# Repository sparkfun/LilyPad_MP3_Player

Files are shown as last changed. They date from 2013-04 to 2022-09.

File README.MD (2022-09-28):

SparkFun LilyPad MP3
========================================

SparkFun LilyPad MP3 (https://www.sparkfun.com/products/11013)

[*SparkFun LilyPad MP3 (DEV-11013)*](https://www.sparkfun.com/products/11013)

The LilyPad MP3 Player is an amazing little board that contains everything you need to play almost any audio file you wish. You can use it to create MP3-playing hoodies, talking teddy bears, or anything else your imagination can come up with!

### Installation:

You should install the latest version of the Arduino IDE, available at http://www.arduino.cc.

This software requires several nonstandard libraries:
	SdFat (by William Greiman)
	SFEMP3Shield (by Bill Porter)
	pinChangeInt (by Lex Talionis)
	
	The current version of these libraries as of this date are included in this archive.

**TL;DR:** The one-step procedure is to drag the contents of the Arduino folder to your personal Arduino sketch folder. This will create a "libraries" folder (containing support libraries), and a "LilyPad MP3 Player" folder (containing example sketches).

To install the libraries manually, copy the "libraries" folder to your personal Arduino sketch directory. (If there is already a "libraries" folder there, go ahead and add the included libraries to it.) You'll need to restart the Arduino IDE to get it to recognize the new libraries.

To install the example sketches, copy the "LilyPad MP3 Player" folder to your personal Arduino sketch folder.

Loading the sketches:

To load a sketch onto the LilyPad MP3 Player:

1. Connect the LilyPad MP3 Player to your computer using a 5V FTDI board or cable (available at http://www.sparkfun.com). Turn the LilyPad MP3 Player ON. The red LED should light up. Note that a Lipo battery or external power source is required to run the LilyPad MP3 Player.

2. Start the Arduino IDE.

3. Select the correct board type from the menu: Tools / Board / "Arduino Pro or Pro Mini (3.3V, 8MHz) w/ATmega328"

4. Select the correct serial port from the menu: Tools / Serial Port / (the port that your FTDI board or cable has created, usually the highest number)

5. Load the desired sketch into the Arduino IDE.

6. Click on the Upload (right arrow) button at the top of the window. The code should compile then upload to the LilyPad MP3 Player. If you have errors, double-check that you installed the required libraries to the correct place, and restarted the Arduino IDE.

See the tutorials at www.sparkfun.com for more information on using and hacking the LilyPad MP3 Player.

Documentation
--------------
* **[Installing an Arduino Library Guide](https://learn.sparkfun.com/tutorials/installing-an-arduino-library)** - Basic information on how to install an Arduino library.
* **[Hookup Guide](https://learn.sparkfun.com/tutorials/getting-started-with-the-lilypad-mp3-player)** - Basic hookup guide.

License Information
-------------------

This product is _**open source**_! 

Please review the LICENSE.md file for license information. 

If you have any questions or concerns on licensing, please contact support@sparkfun.com.

Distributed as-is; no warranty is given.

- Your friends at SparkFun.

_<COLLABORATION CREDIT>_

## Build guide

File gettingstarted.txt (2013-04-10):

SparkFun Electronics
LilyPad MP3 Player
Getting started guide (DRAFT)

The LilyPad MP3 Player is an amazing little board that contains everything you need to play almost any audio file you wish. You can use it to create MP3-playing hoodies, talking teddy bears, or anything else your imagination can come up with!

Things you'll need

A 5V FTDI BOB or cable
A single-cell (3.7V) Lipo battery (500mAh or above recommended)
Two 4 or 8-Ohm Speakers, or headphones with a 1/8" stereo jack
Conductive thread and sewing supplies, or hook-up wire and soldering tools

Getting started with the default sketch ("Trigger")

The default sketch will wait for one of the five trigger inputs to be grounded, and play the corresponding audio file from the micro-SD card.

1. Put up to five audio files onto a micro-SD card. The board will play a number of audio formats including MP3, WAV, AAC, MID, etc.

2. Rename the files so that the first character of each filename is the number "1" to "5", corresponding to the trigger that you want to play that file. You don't need to change anything else about the filename; just make sure it has one of the standard file extensions for audio types (MP3, WAV, AAC, MID, etc.).

3. Turn off the LilyPad MP3 Player and plug your micro-SD card into the socket. Push it in until it clicks; if you release it, it will stay seated. To remove it, push again until it clicks, and it will pop out when you release it.

4. Connect a headphone to the headphone jack*, or connect speakers to the left and right speaker terminals. (Note that when anything is plugged into the headphone jack, the speaker terminals are disabled. This behavior can be changed if desired).

5. Plug a 3.7V single-cell Lipo battery into the JST connector. Note that a FTDI USB connection will not provide enough power to run the board**, so a battery or other external power source is required.

6. Move the power switch to ON. The red LED should light up.

7. Now, momentarily connect the ground sew tap (marked GND) to one of the trigger terminals (marked T1 through T5). The audio file associated with that terminal should play through the speakers / headphone. If you don't hear anything, see the troubleshooting section below.

8. To charge the battery or reprogram the board, connect a 5 volt FTDI board to the FTDI header. The yellow LED will light up while the battery is charging, and go out when it's full. To reprogram the board, make sure it's turned on.

9. Have fun!

Getting started with the "Player" sketch

The "Player" sketch is not preprogrammed onto the LilyPad MP3 Player, but you can easily install it using the free Arduino IDE. It is included with the LilyPad MP3 software which you can download from the product page at SparkFun.com.

The Player sketch turns the LilyPad MP3 Player into a full audio player, allowing you to easily switch between tracks and change the volume. The user interface is a rotary encoder (a knob with a built-in pushbutton) available from SparkFun.com that you'll solder onto the LilyPad MP3 Player board.

Things you'll need to run the Player sketch:

RGB Rotary Encoder (SparkFun part no. COM-10982)
(Optional) Clear Plastic Knob (SparkFun part no. COM-10597)
Soldering tools

1. Insert the Rotary Encoder's pins into the holes in the center of the LilyPad MP3 Player. Note that it goes into the "top" side of the board (the side with the white outline).

2. Flip the board over, and solder the encoder's pins to the board. (Don't know how to solder? It's easy, see the tutorials at SparkFun.com).

3. If you haven't, install the free Arduino IDE available from www.arduino.cc, and install the LilyPad MP3 Player software available from SparkFun.com. Note that several new libraries will need to be copied to your "libraries" folder.

4. Connect a 5V FTDI board or cable to the LilyPad MP3 Player, turn on the power switch on the board, and use the Arduino IDE to upload the "Player" sketch to the board.

5. Place the audio files of your choice on a micro-SD card. The LilyPad MP3 Player understands a wide variety of audio types; just make sure your files have one of the standard file extensions (MP3, WAV, AAC, MID, etc.).

6. Turn off the LilyPad MP3 Player, and plug your micro-SD card into socket. Push it in until it clicks; if you release it, it will stay seated. To remove it, push again until it clicks, and it will pop out when you release it.

7. Connect a headphone to the headphone jack*, or connect speakers to the left and right speaker terminals. (Note that when anything is plugged into the headphone jack, the speaker terminals are disabled. This behavior can be changed if desired).

8. Plug a 3.7V single-cell Lipo battery into the JST connector. Note that a FTDI USB connection will not provide enough power to run the board**, so a battery or other external power source is required.

9. Move the power switch to ON. The red LED should light up, and after a few seconds, the rotary encoder will turn red, indicating the player is in "track" mode. (If the rotary encoder blinks, there was a startup problem, see the troubleshooting tips below.)

10. Play music! Here's how:

At any time, to start and stop playback, briefly press the rotary encoder button. When a track has finished playing, the next track will automatically start.

To switch between "track" and "volume" modes, hold the rotary encoder button down until the color changes (one second). Red = track mode, green = volume mode.

In track mode, you can turn the knob forwards or backwards to change tracks (one track per "click" of the knob). If you're currently playing, turning the knob will stop the current track and switch to the next / previous one. If you're not playing, the player will silently keep track of how many clicks you've made.

In volume mode, you can turn the knob forwards or backwards to change the volume.

11. To charge the battery or reprogram the board, connect a 5 volt FTDI board to the FTDI header. The yellow LED will light up while the battery is charging, and go out when it's full. To reprogram the board, make sure it's turned on.

12. Have fun!

Notes

* The LilyPad MP3 Player's headphone jack is safe for headphones, but don't connect it to an external amplifier unless you're using a battery to power the LilyPad. (The fine print is that if the audio ground is shorted to the power ground, the audio decoder chip will be damaged).

** The FTDI port is provided to charge an attached Lipo battery and provide a way to reprogram the board. It will power the board if no audio is playing, but will not provide enough power to drive the speakers. In general, the best way to power the LilyPad MP3 Player is with a Lipo battery. If you'd like to use an external 3.5V - 6V supply, you can do so through the battery connector.

More about the connections

Triggers

In the default Trigger sketch, the five trigger inputs are used to start playing a selected audio file. These inputs are triggered when they are connected to the ground pin (GND), and remain untriggered if they are left "open" or disconnected. You can connect the triggers to ground through “soft switches” to allow your project to play audio clips!

Aside from being triggers, all of the trigger pins have alternate uses. When you write your own sketches, you can use these pins to connect to other devices such as accelerometers, displays, etc.

T1	Trigger 1 input. This can also be used as an analog input (A0).
T2	Trigger 2 input. This can also be used with the Wire (I2C) library as the SDA pin.
T3	Trigger 3 input. This can also be used with the Wire (I2C) library as the SCL pin.
T4	Trigger 4 input. This can also be used as a serial TX pin.
T5	Trigger 5 input. This can also be used as a serial RX pin.

Note that triggers 4 and 5 are shared by the Arduino's serial port, which is used to upload sketches to the board. You can leave soft switches connected to these triggers and upload sketches to the board AS LONG AS the switches stay "untriggered" (not connected to ground) WHILE you're uploading code.

Power

Normally, you'll just connect a 3.7V Lipo battery to the LilyPad MP3 Player, and won't need any of the additional power connections (except the ground pin for your triggers). But if you want to power the board some other way, these pins give you options to do so.

If you already have a regulated 3.3V supply, you can connect it to the 3.3V pin. (This pin will also provide a regulated 3.3V output when the board is operating.) Note that the LilyPad MP3 Player can draw several hundred milliamps when running at full volume.

If you have an unregulated supply in the 3.5V to 6V range, and you want to use it to charge an attached Lipo battery, you can connect it to the VIN pin. If you want to use a 3.5V to 6V source instead of a Lipo battery, connect it to the battery connector or +/- header next to the connector. (This will bypass the charge circuitry). Don't connect a power source to the battery terminals while a battery is connected.

GND	Common ground connection
VIN	Input to battery charger (also connected to FTDI VCC pin)
Battery	Input to circuitry (do not connect a battery at the same time) 
3.3V	Regulated 3.3V input or output

Speakers

The LilyPad MP3 Player includes a stereo class-D audio amplifier for driving speakers. It will drive speakers from 4 to 16 ohms, and the amplifier can output up to 0.75 watts per channel.

We've had good luck with speakers of all sizes, but in general larger speakers will sound better. (TIP: You can often make smaller speakers sound better if you put some sort of enclosed cavity behind them). You can also connect multiple speakers in series or parallel for each channel, as long as the total load is between 4 and 16 ohms.

The speaker outputs are a high-efficiency PWM signal designed only for speakers. Don't connect the speaker outputs to anything besides speakers or other coil-based transducers. Also ensure that you don't connect the speaker outputs together, to each other, or to ground.

If you want to connect the LilyPad MP3 Player to an external amplifier, you can use the headphone jack, but be careful: the audio ground is not the same as the power ground, and if those two are connected the MP3 decoding chip will be damaged. This generally means that the LilyPad MP3 Player and your external amplifier should be running on separate power supplies. If you're running the LilyPad on a Lipo battery, this should be safe. Note that if you're exclusively using the headphone jack, you can disable the amplifier in your sketch to save power.

TIP: Speakers have two terminals, sometimes they're labeled + and -, and sometimes they're not labeled at all. Speakers are non-polarized; they'll work equally well connected in either direction, but if you're using more than one speaker, try to connect both of them the same way. If one is reversed from the other, you may hear strange phasing effects in the audio (which might be what you want after all!).

Battery charging

To charge an attached Lipo battery, plug a 5V FTDI board or cable into the FTDI header. The battery will charge whether the board is on or off, but the battery will charge somewhat faster while the board is off.

The yellow charge LED will light while the battery is charging, and go out when the battery is full. It is normal for the charge LED to light if there is no battery connected.

When an empty battery starts charging, the charger chip will get warm. This is normal. It will run cooler as the battery approaches full charge.

The battery charger is set to a charge rate of 500mA (the maximum provided by a USB port). This means that an empty 500mAh battery will recharge in one hour; a 1000mAh battery will recharge in two hours, etc.

If you wish, you can change the charge rate by changing resistor R1. You may want to do this to avoid charging the battery too quickly if you're using a smaller battery than 500mAh. (SparkFun Lipo batteries do not like to be charged faster than one hour.) To change the charge rate, use a soldering iron to discard the small surface-mount resistor in the box marked R1 near the power switch. Then solder in a through-hole resistor of the proper size. The formula to determine the proper resistance is: R = 1000 / desired current in Amps. For the default current of 500mA (0.5A), a 2000 Ohm resistor is used. If you want to use a 110mAh battery, you'll want a charge rate of 110mA (0.110A), which requires a 9090 Ohm resistor. The closest standard resistor value is 9.1K, but an easier-to-find 10K resistor would give you a charge rate of 100mA, which is safe.

Programming

The LilyPad MP3 Player example sketches require several additional libraries. These libraries are included in the LilyPad MP3 Player archive; before programming the board, drag the libraries from the archive into a "libraries" folder within your Arduino sketch folder.

The LilyPad MP3 Player must be turned ON to program it.

Set your Arduino IDE's Tools/Board setting to "Arduino Pro or Pro Mini (3.3V, 8MHz) w/ ATmega328".

The example code (Trigger and Player) are great starting points for writing your own code. Also see the code in the LilyPad MP3 Player "examples" directory.

Troubleshooting

If the board can't find a properly-formatted SD card, it will blink the red LED in the rotary encoder. (If you don't have a rotary encoder installed, you can stick the leads from a LED into the two end holes in the row of five holes in the rotary encoder footprint.) If this happens, double-check that a micro-SD card is plugged in, and that it's properly formatted (FAT or FAT32).

If the red power LED turns on but you can't get it to play any sounds, double-check that: there are audio files present on the SD card, that the extensions of the files are a playable type (MP3, WAV, etc.), and if you're using the trigger sketch, that the first character in the filename is a number from 1 to 5. Also check that you're making a good connection between GND and the trigger pin (an alligator cable is a good way to check this).

If the player stops in the middle of a song, ensure that you're using a full Lipo battery.

Tips

Note that the board requires a 5V (not a 3.3V) FTDI BOB or cable.

Don't connect the speaker outputs together, to ground, or to anything that isn't a speaker or coil-based transducer.

Use a full battery; if the voltage gets too low the LilyPad MP3 Player may lock up (you can turn it off and on to restart it).

Only insert or eject the SD card when the LilyPad MP3 Player is powered off.

Before washing a garment or project containing the LilyPad MP3 Player, follow these steps:

1.Remove the Lipo battery
2.Remove the micro-SD card
3.Wash by hand
4.Allow to fully air dry (over several days) before powering up again

Have fun!

-Your friends at SparkFun.

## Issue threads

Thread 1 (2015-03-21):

I dont know why this keeps coming up. Help!

jso-07, 2015-03-21:
Arduino: 1.6.1 (Mac OS X), Board: "LilyPad Arduino, ATmega328"

/Users/jasmineangelaso/Documents/Arduino/libraries/SFEMP3Shield/SFEMP3Shield.cpp:25:37: error: variable 'bitrate_table' must be const in order to be put into read-only section by means of '__attribute__((progmem))'
 PROGMEM uint16_t bitrate_table[15][6] = {
                                     ^
Error compiling.

  This report would have more information with
  "Show verbose output during compilation"
  enabled in File > Preferences.

embeddedgenius, 2015-08-12:
I'm getting this error as well.  How do you resolve this?

mgrusin, 2016-02-29:
We've updated the SFE MP3 Player library included in this repository to the most recent version, which fixes the above issue and should compile cleanly in recent Arduino IDEs (1.6.7 etc.) Please let us know if you run into further problems.

Closed 2016-02-29.

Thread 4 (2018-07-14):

Player - 'Next Track' issues

Joshoeah, 2018-07-14:
Hi there,

As discussed with Sparkfun support, Player.ino appears to have issues with moving to the next track. Using a Lilypad MP3 with two speakers connected and an SD Card formatted to FAT32 with 7 files on it (all MP3):

**Whilst playing**
-  Turning rotary encoder CW results in it skipping from whichever track is playing to Track 1, then Track 5, then Track 1, then back to Track 5 - it never selects any other track.

- Allowing a track to play through and 'advance' to the next one automatically results in the same behaviour - Track 1, 5, 1, 5 over and over.

- Turning rotary encoder CCW results in skipping to 'previous' track exactly as expected. I anticipate this is due to the different code used to search 'backwards' through the SD card.

**Whilst not playing** (monitored through Serial)
- Turning rotary encoder either direction results in the device correctly moving through tracks sequentially - exactly as expected.

I have observed no other issues outside of this - though looking through the code I simply cannot see why I'm experiencing this problem. I have even monitored HEX values of the encoder and these are consistent - whether playing or not - so it does not appear to be an issue with the encoder or the code controlling it. Rather, it appears this issue is with selecting the next file on the SD Card.

I have noticed some of the libraries have been updated since this code was posted here and on the Sparkfun site - I tried to update these in the Arduino IDE, but this resulted in errors regarding SDFatUtil and the code would no longer compile.

Hope that's enough information for you / you might be able to help with narrowing this issue down - I'm a bit lost!

mgrusin, 2018-07-14:
Hi Josh, that's an excellent bug report, and a mysterious one. I'll be sure to take a look at this next week, but in the meantime you might turn on serial debugging output at the top of the code to see if it prints out any clues. There could also be something weird with the SD card. You might try low-level formatting it, and also see if you can read all the files off of it on a normal computer.

Joshoeah, 2018-07-14:
Hey Mike - thanks for the help. Can confirm I've formatted the SD card a few times on various computers just to check and tried an alternative one too - had no luck either way so far. Serial debugging doesn't seem to show up anything unusual - everything starts up as expected with no error messages. Switching between tracks (whether CW or CCW) whilst playing gives the usual 'Stopping playback' and then next file name.
Just in case - I'll grab a fresh SD card and try some alternative files and will reply here if I have any luck. Thanks in advance for any light you might be able to shed on the matter! Let me know if I can pull any extra info from the serial monitor for you.

Joshoeah, 2018-07-14:
Quick update: fresh 1GB SD, tested formatted as both FAT and FAT32 - exactly the same behaviour, no changes in either case.

mgrusin, 2018-07-16:
Hi Josh, give the Rotary_Encoder_Demo.ino a try (in examples) when you get a chance. With the serial window open to 9600 baud it should show smooth operation of the rotary encoder. If it doesn't there may be a hardware problem with the encoder, which could explain some of this behavior.

It's worth noting that the player sketch doesn't do any alphabetizing of the files it finds; it plays them in the order in which they're physically stored on the SD card. To get them to play in a specific order you might try formatting the card then copying your files to it one-by-one in the order you prefer.

The way player works, especially when you want the previous file (for which there is no SDfat function) was always a little hacky due to the primitive way SDfat traverses directories. I do recall seeing that SDfat had completely changed some of their routines (hopefully for the better) but since that thoroughly broke the existing software we haven't gone back to rewrite everything. It might be time to do that now. But if you use all of the libraries included in this repo (deleting newer ones from your libraries folder to avoid confusion) it "should" work.

Let me know what you find.

Joshoeah, 2018-07-16:
Hey Mike, I gave Rotary_Encoder_Demo.ino a shot just now and the encoder spins smoothly - numbers increase as far as I turn it, then decrease the other way. No issues with button press (or hold) - all behaving as expected.

Ahh I got'cha - I did wonder! Either way, moving forward (CW) whilst playing just runs the first three tracks it finds on the card (1, 6, then 2 in this case) before looping back to 1 again. The things I find most strange is getNextTrack clearly has no issues moving through files - it smoothly moves from track to track when playback is paused as well as when moving backwards through the tracks (CCW on the encoder).

I've since reverted to the libraries you have here as suggested. I don't think I'm capable enough to rewrite this with the new libraries - I got lost when I did try - but I could try and hack something together. The prop I'm building is for an event on the 5th of August, so if necessary I'll just ensure it's used to skip through tracks backwards and forego going forwards - only problem with this being when it reaches the end of a track it'll revert back to the 1,2,6 loop. If all else fails I might just have to make a singular long MP3 with all of the files in the order required - that'll work 100% :)

Thanks for the help!

Joshoeah, 2018-07-17:
Okay - got it! Managed to get it to compile using the latest version of SdFat (updated direct from the Library Manager) and **that's fixed it!** Tracks now smoothly advance sequentially whether using the encoder or when reaching the end of a track.

Steps taken for future reference (probably hacky, but hey, it works):

- Removed \#include SdFatUtil.h from **SFEMP3Shield.h** - not used in new SdFat library
- Removed \#include SdFatUtil.h from **Player.ino** - not used in new SdFat library
- Changed **Line 611 in Player.ino**, amending file.getFileName(track) to file.getName(track,13). This is the key change that got it working with the new SdFat, since getFileName has been deprecated. file.getName has a new parameter for length, hence the 13. Not sure if this is the right way to do it, but it works!

Worth noting that SdFat now supports long names, so the full track name could be pulled - if this is of use to anyone in the future.

I did have a funny issue with 'FreeRam' in line 186 - the code would no longer compile and started throwing errors about this not being defined. Since it wasn't critical, I've just commented it out for now.

Hope this helps anybody in future - the changes were ultimately quite simple to make and the sketch now works perfectly!

Joshoeah, 2018-07-18:
Quick supplementary comment to this - my files were ultimately stored with the naming format 1.mp3, 2.mp3, 3.mp3, etc... I found that longer names were a bit unreliable and could result in the track being skipped. **I imagine this is due to me specifying length parameter as '13'** - though I admittedly have not had chance to check since the Lilypad has been secured into the prop.

**I also noted issues with tracks not starting immediately** - seemingly taking a long time to 'load', with several seconds of silence between them. **This was resolved by using [MP3tag](https://www.mp3tag.de/en/index.html) to strip every bit of metadata**, including any cover art, from the files. After doing so I found files loaded instantly and skipping / playing seemed far more responsive.

mgrusin, 2018-07-18:
Hi Josh, well done! I'm very glad you got it working, and thank you for giving us the steps it took to do so. I believe your solution will work as long as you don't have two filenames that share the same first 13 characters; otherwise it may have problems finding the previous file. But that's an easy enough restriction to work around. When I have time I'll dig into the new SDfat and update everything. Thanks again and again nicely done.

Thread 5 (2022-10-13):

playMP3(fileName, timecode)

JonGordon123, 2022-10-13:
Arduino 1.8.19
LilyPad MP3

I was having a few issues when attempting to play an mp3 from a specified ms time and found the following.

1) The variable "**bitrate**" is declared in SFEMP3Shield.h as a uint8_t, which only allows bitrates up to 224kbps. I changed it to uint16_t which solves that issue.

2) The If...else if... else if... else statement found in the **getBitRateFromMP3File(filename)** function (SFEMP3Shield.cpp) seems to not be functioning as, I imagine, it should be. If the MP3 file is MPEG Version 2/2.5 then the first if statement evaluates true, and no other code is run in the if/else if block.... causing the "bitrate" variable to be filled with an incorrect bitrate.
I tested with multiple files, bitrates, and sample rates and was getting incorrect bitrates often.
```
 //found the 11 1's
  //parse version, layer and bitrate out and save bitrate
  if(!(temp & 0b00001000)) { //!true if Version 1, !false version 2 and 2.5
    row_num = 3;
  }
  else if((temp & 0b00000110) == 0b00000100) { //true if layer 2, false if layer 1 or 3
    row_num += 1;
  }
  else if((temp & 0b00000110) == 0b00000010) { //true if layer 3, false if layer 2 or 1
    row_num += 2;
  } else {
    continue; // Not found, need to skip the rest and continue looking.
              // \warning But this can lead to a dead end and file end of file.
  }
```

**I seem to have fixed my issue by replacing the existing if...else if....else if...else with the following.**

```
bool nobits = true;

if(!(temp & 0b00001000)) {
   // MPEG Version 2 or 2.5
   row_num = 3;
   nobits = false;
}
if((temp & 0b00000110) == 0b00000110) {
  // Layer 1
  row_num += 0;
  nobits = false;
}
if((temp & 0b00000110) == 0b00000100) {
  // Layer 2
  row_num += 1;
  nobits = false;
}
if((temp & 0b00000110) == 0b00000010) {
  // Layer 3
  row_num += 2;
  nobits = false;
}
if(nobits){
  continue;
}
```

These two changes allowed me to play any file from any ms timestamp, without issue.

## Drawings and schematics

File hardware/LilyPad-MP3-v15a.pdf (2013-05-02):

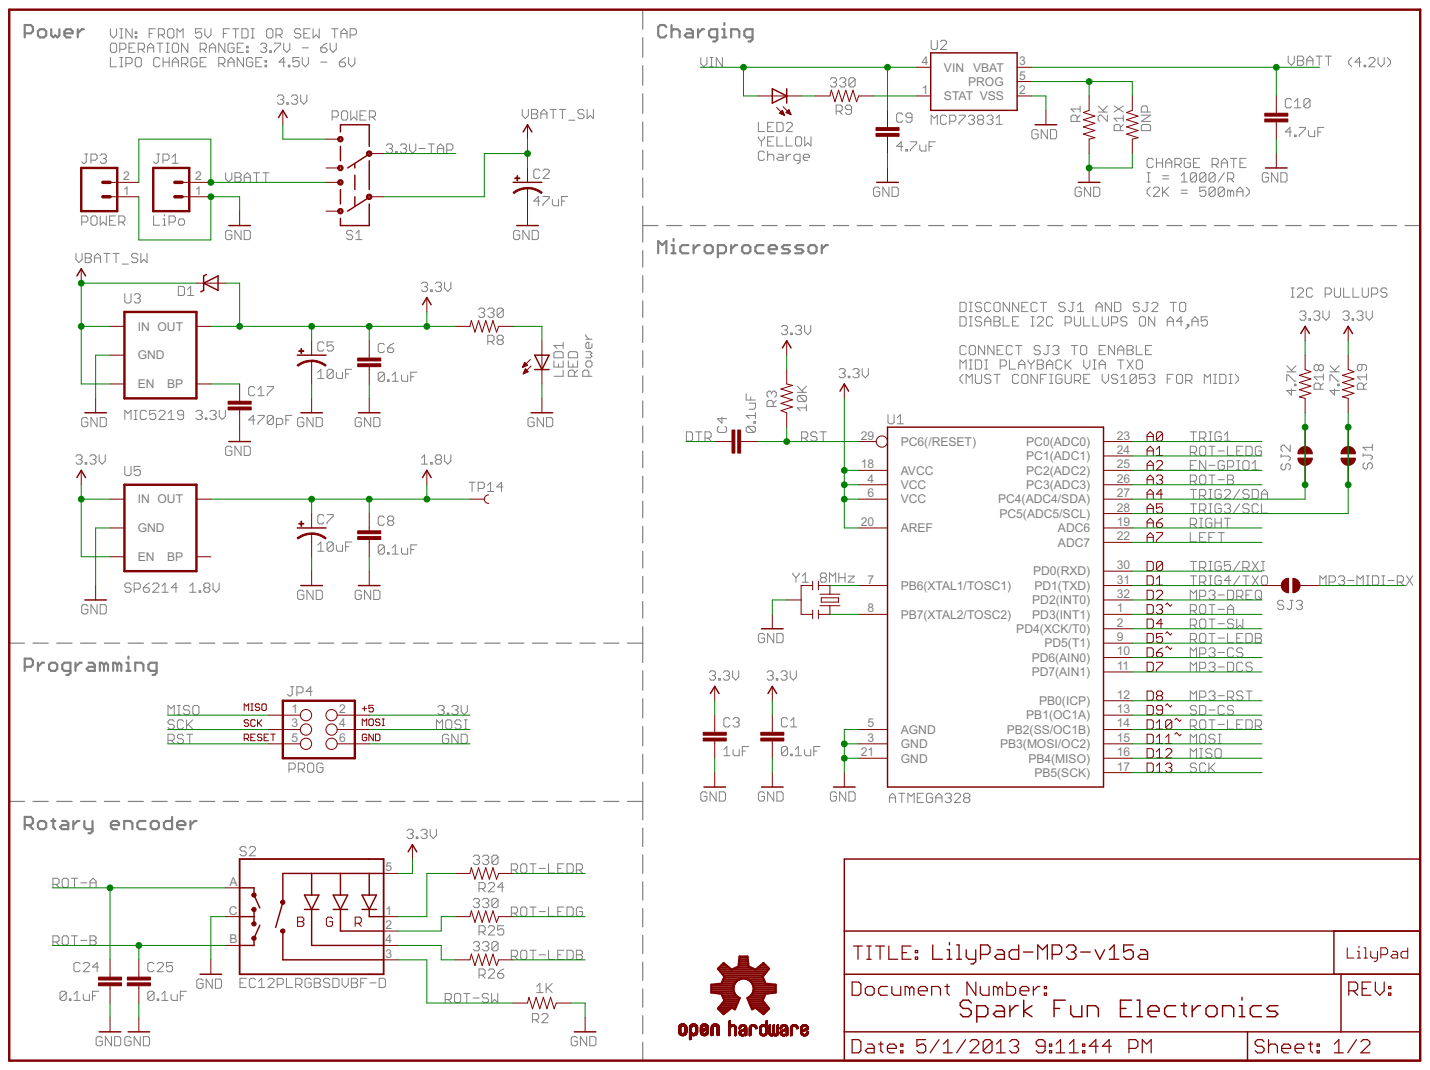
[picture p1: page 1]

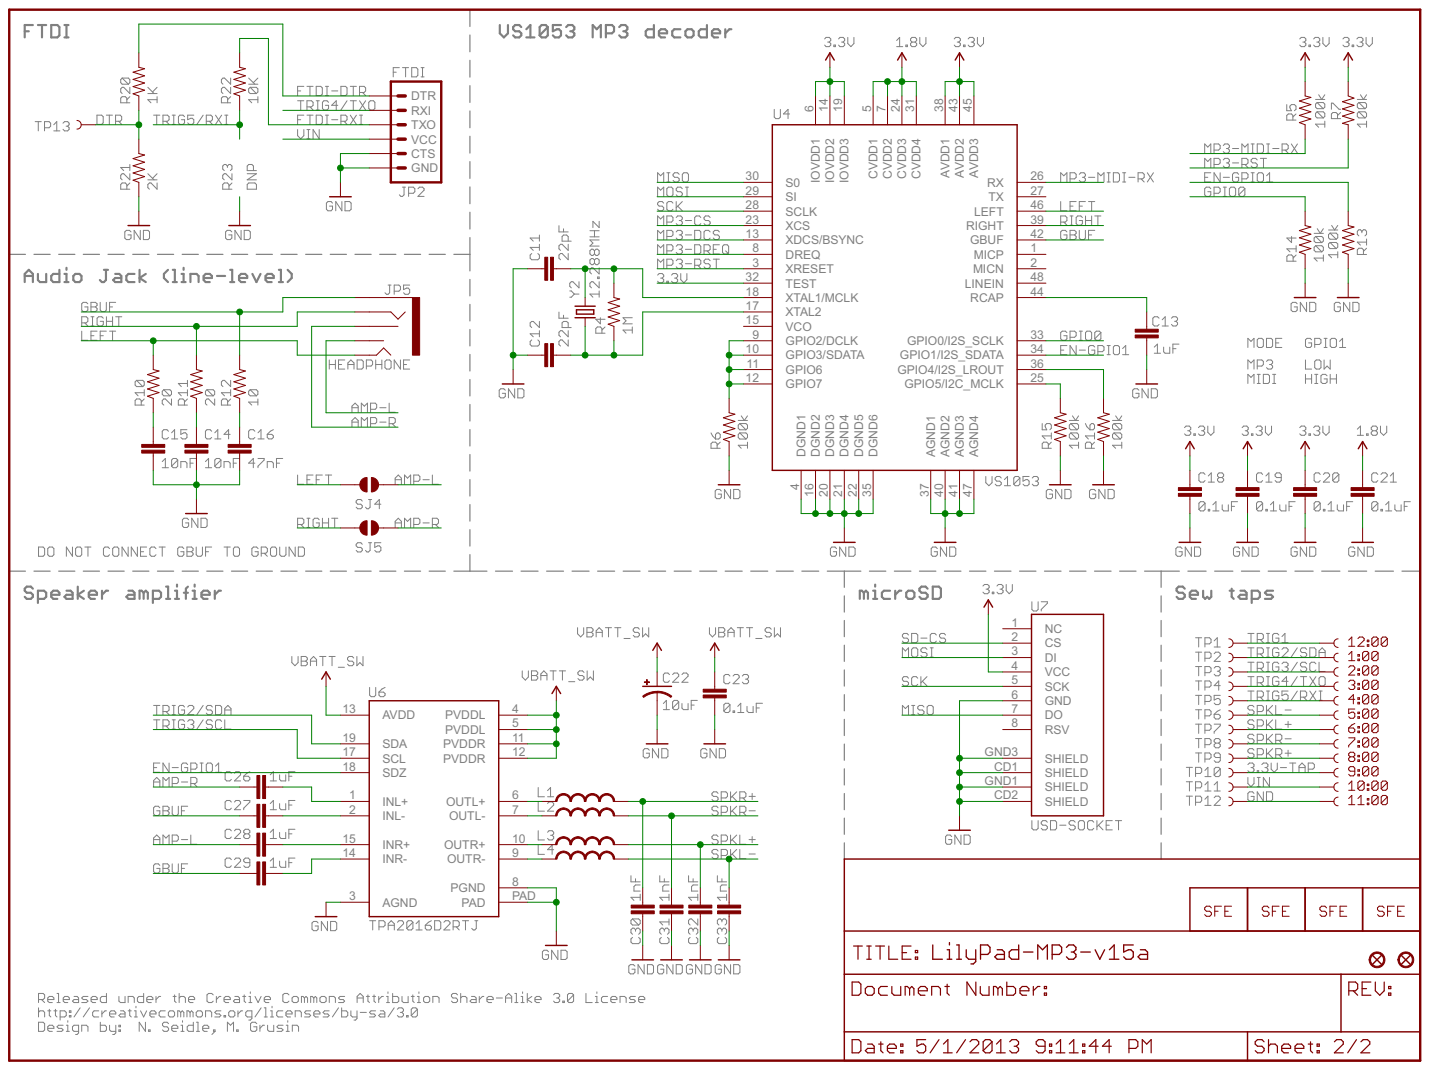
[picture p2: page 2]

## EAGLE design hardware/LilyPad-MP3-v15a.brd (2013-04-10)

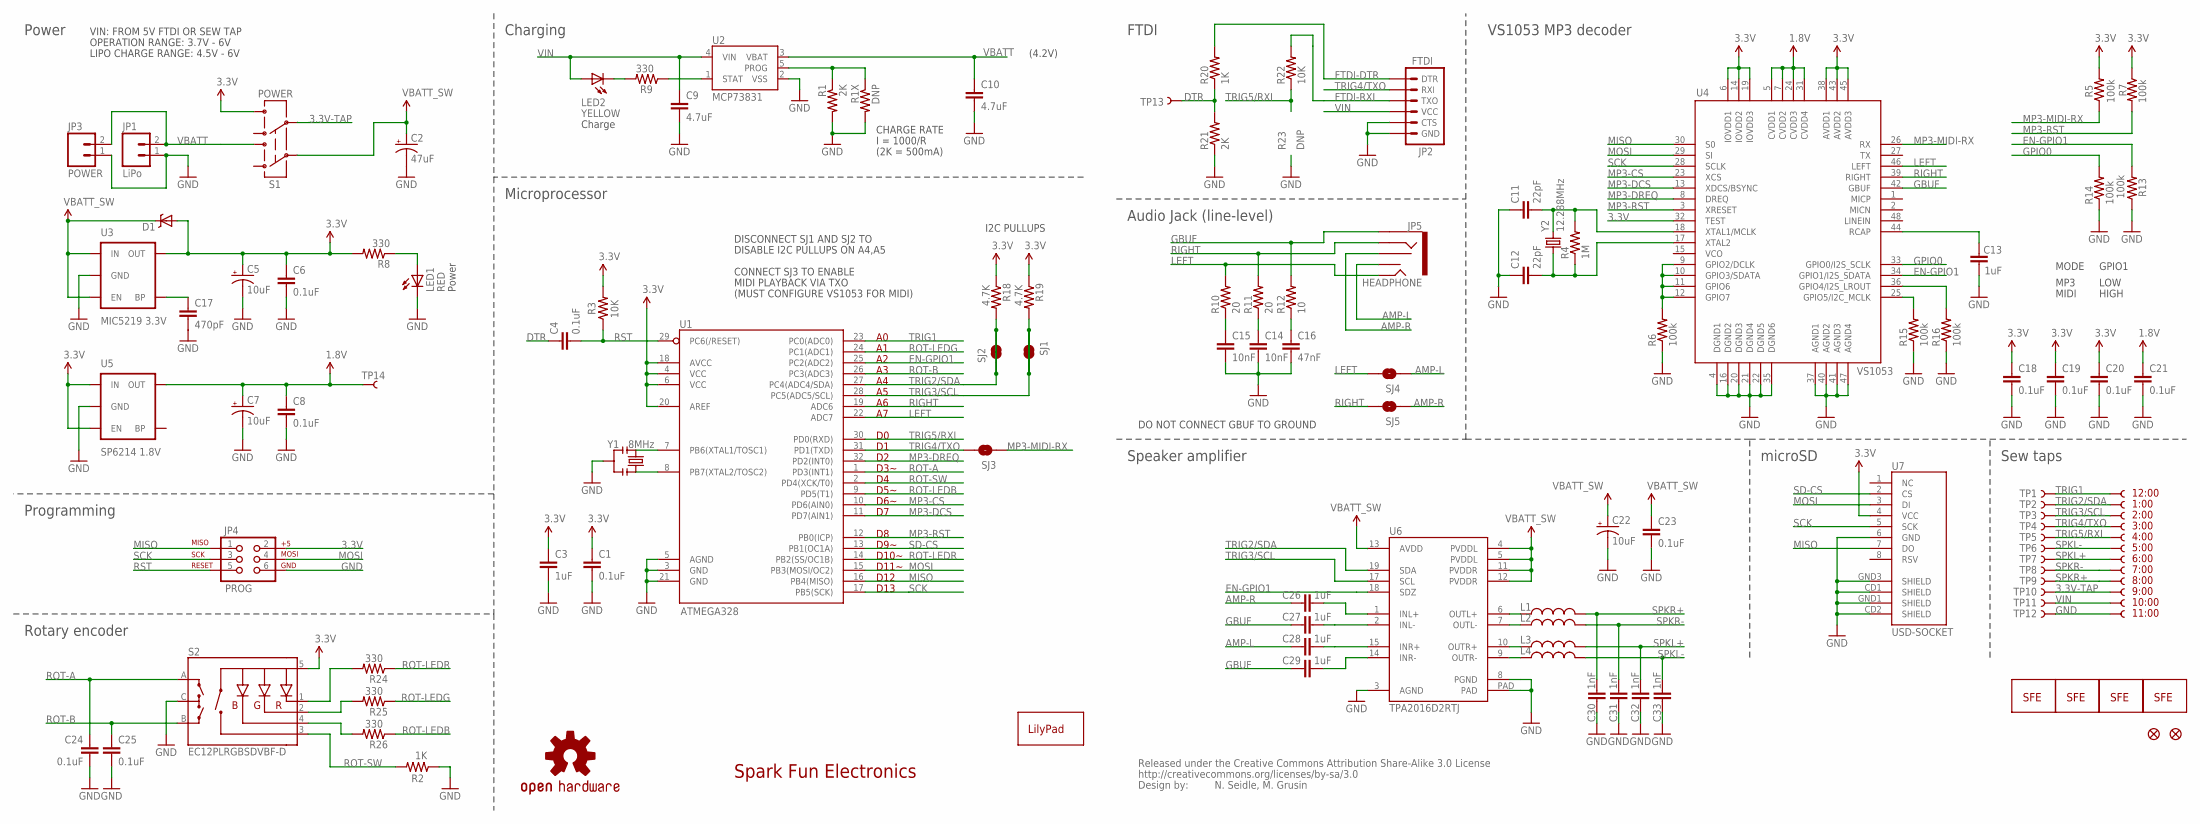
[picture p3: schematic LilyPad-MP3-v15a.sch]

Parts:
C1, C4, C6, C8, C18, C19, C20, C21, C23, C24, C25: 0.1uF; 0402-CAP
C2: 47uF; EIA3528
C3, C13, C26, C27, C28, C29: 1uF; 0402-CAP
C5, C7, C22: 10uF; EIA3216
C9, C10: 4.7uF; 0402-CAP
C11, C12: 22pF; 0402-CAP
C14, C15: 10nF; 0402-CAP
C16: 47nF; 0402-CAP
C17: 470pF; 0402-CAP
C30, C31, C32, C33: 1nF; 0402-CAP
D1: DIODE-SCHOTTKY; SOD-523
JP1: LiPo; JST-2-SMD
JP2: FTDI; 1X06-SMD
JP3: POWER; 1X02
JP4: PROG; 2X3-NS
JP5: HEADPHONE; AUDIO-JACK-3.5MM-SMD
JP6: LOGO-SFENW2; SFE-NEW-WEB
JP7, JP8: FIDUCIALUFIDUCIAL; MICRO-FIDUCIAL
L1, L2, L3, L4: INDUCTOR0805; 0805
LED1: RED; LED-0603
LED2: YELLOW; LED-0603
LOGO1, LOGO3: LOGO-SFESK; SFE-LOGO-FLAME
LOGO2: LOGO-SFENEW; SFE-NEW-WEBLOGO
R1, R21: 2K; 0402-RES
R1X: DNP; AXIAL-0.3
R2, R20: 1K; 0402-RES
R3, R22: 10K; 0402-RES
R4: 1M; 0402-RES
R5, R6, R7, R13, R14, R15, R16: 100k; 0402-RES
R8, R9, R24, R25, R26: 330; 0402-RES
R10, R11: 20; 0402-RES
R12: 10; 0402-RES
R18, R19: 4.7K; 0402-RES
S1: POWER; AYZ0202
S2: EC12PLRGBSDVBF-D; ENCODER_LED_3
SJ1, SJ2, SJ3, SJ4, SJ5: SOLDERJUMPERNO; SJ_2S-NO
ST1: TRIG2/SDA; PETAL-LONG-1-2SIDE
ST2: TRIG3/SCL; PETAL-LONG-1-2SIDE
ST3: TRIG4/TXO; PETAL-LONG-1-2SIDE
ST4: TRIG5/RXI; PETAL-LONG-1-2SIDE
ST5: SPKL-; PETAL-LONG-1-2SIDE
ST6: SPKL+; PETAL-LONG-1-2SIDE
ST7: SPKR-; PETAL-LONG-1-2SIDE
ST8: SPKR+; PETAL-LONG-1-2SIDE
ST9: 3.3V; PETAL-LONG-1-2SIDE
ST10: VIN; PETAL-LONG-1-2SIDE
ST11: GND; PETAL-LONG-1-2SIDE
ST12: TRIG1; PETAL-LONG-1-2SIDE
TP1: TRIG1; 1X01NS
TP2: TRIG2/SDA; 1X01NS
TP3: TRIG3/SCL; 1X01NS
TP4: TRIG4/TXO; 1X01NS
TP5: TRIG5/RXI; 1X01NS
TP6: SPKL-; 1X01NS
TP7: SPKL+; 1X01NS
TP8: SPKR-; 1X01NS
TP9: SPKR+; 1X01NS
TP10: 3.3V; 1X01NS
TP11: VIN; 1X01NS
TP12: GND; 1X01NS
TP13: DTR; PAD.03X.05
TP14: 1.8V; PAD.03X.05
U1: ATMEGA328; TQFP32-08
U2: MCP73831; SOT23-5
U3: MIC5219 3.3V; SOT23-5
U4: VS1053; LQFP-48
U5: SP6214 1.8V; SC70
U6: TPA2016D2RTJ; QFN-20-0.5MM
U7: USD-SOCKET; MICRO-SD-SOCKET-PP
U$1: LOGO-LPLP; LOGO-LILYPAD
U$4: OSHW-LOGOM; OSHW-LOGO-M
U$12: CREATIVE_COMMONS
Y1: 8MHz; RESONATOR-SMD
Y2: 12.288MHz; CRYSTAL-SMD-5X3

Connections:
1.8V: C7.A (+), C8.1, C21.1, TP14.P$1, U4.5 (CVDD1), U4.7 (CVDD2), U4.24 (CVDD3), U4.31 (CVDD4), U5.5 (OUT)
3.3V: C1.1, C3.1, C5.A (+), C6.1, C18.1, C19.1, C20.1, D1.A, JP4.2, R3.2, R5.2, R7.1, R8.2, R18.1, R19.1, S1.4 (6), S2.5 (+), U1.4 (VCC), U1.6 (VCC), U1.18 (AVCC), U1.20 (AREF), U3.5 (OUT), U4.6 (IOVDD1), U4.14 (IOVDD2), U4.19 (IOVDD3), U4.32 (TEST), U4.38 (AVDD1), U4.43 (AVDD2), U4.45 (AVDD3), U5.1 (IN), U5.3 (EN), U7.4 (VCC)
3.3V-TAP: S1.5, ST9.1, TP10.1
AMP-L: C28.1, JP5.TSH, SJ4.1
AMP-LX: C26.2, U6.1 (INL+)
AMP-R: C26.1, JP5.RSH, SJ5.1
AMP-RX: C28.2, U6.15 (INR+)
DTR: C4.1, R20.1, R21.2, TP13.P$1
EN-GPIO1: R13.2, U1.25 (PC2(ADC2)), U4.34 (GPIO1/I2S_SDATA), U6.18 (SDZ)
FTDI-DTR: JP2.1 (DTR), R20.2
FTDI-RXI: JP2.3 (TXO), R22.2
G1: R6.2, U4.9 (GPIO2/DCLK), U4.10 (GPIO3/SDATA), U4.11 (GPIO6), U4.12 (GPIO7)
G2: R15.2, U4.25 (GPIO5/I2C_MCLK)
GBUF: C27.1, C29.1, JP5.SLEEVE, R12.2, U4.42 (GBUF)
GBUFLX: C27.2, U6.2 (INL-)
GBUFRX: C29.2, U6.14 (INR-)
GND: C1.2, C2.C (-), C3.2, C5.C (-), C6.2, C7.C (-), C8.2, C9.2, C10.2, C11.1, C12.1, C13.1, C14.2, C15.2, C16.2, C17.2, C18.2, C19.2, C20.2, C21.2, C22.C (-), C23.2, C24.2, C25.2, C30.2, C31.2, C32.2, C33.2, JP1.1, JP2.5 (CTS), JP2.6 (GND), JP3.1, JP4.6, LED1.C, R1.2, R1X.P$2 (2), R2.1, R6.1, R13.1, R14.1, R15.1, R16.1, R21.1, S2.C, ST11.1, TP12.1, U1.3 (GND), U1.5 (AGND), U1.21 (GND), U2.2 (VSS), U3.2 (GND), U4.4 (DGND1), U4.16 (DGND2), U4.20 (DGND3), U4.21 (DGND4), U4.22 (DGND5), U4.35 (DGND6), U4.37 (AGND1), U4.40 (AGND2), U4.41 (AGND3), U4.47 (AGND4), U5.2 (GND), U6.3 (AGND), U6.8 (PGND), U6.PAD, U7.6 (GND), U7.CD1 (SHIELD), U7.CD2 (SHIELD), U7.GND1 (SHIELD), U7.GND3 (SHIELD), Y1.2
GPIO0: R14.2, U4.33 (GPIO0/I2S_SCLK)
LEFT: JP5.TIP, R10.2, SJ4.2, U1.22 (ADC7), U4.46 (LEFT)
MISO: JP4.1, U1.16 (PB4(MISO)), U4.30 (S0), U7.7 (DO)
MOSI: JP4.4, U1.15 (PB3(MOSI/OC2)), U4.29 (SI), U7.3 (DI)
MP3-CS: U1.10 (PD6(AIN0)), U4.23 (XCS)
MP3-DCS: U1.11 (PD7(AIN1)), U4.13 (XDCS/BSYNC)
MP3-DREQ: U1.32 (PD2(INT0)), U4.8 (DREQ)
MP3-MIDI-RX: R5.1, SJ3.1, U4.26 (RX)
MP3-RST: R7.2, U1.12 (PB0(ICP)), U4.3 (XRESET)
unnamed: U1.7 (PB6(XTAL1/TOSC1)), Y1.1
unnamed: U1.8 (PB7(XTAL2/TOSC2)), Y1.3
unnamed: C13.2, U4.44 (RCAP)
unnamed: C16.1, R12.1
unnamed: LED1.A, R8.1
unnamed: C15.1, R10.1
unnamed: LED2.C, R9.2
unnamed: C11.2, R4.2, U4.18 (XTAL1/MCLK), Y2.3 (2)
unnamed: C12.2, R4.1, U4.17 (XTAL2), Y2.1
unnamed: C14.1, R11.1
unnamed: R24.2, S2.1 (-R)
unnamed: R25.2, S2.2 (-G)
unnamed: R26.2, S2.4 (-B)
unnamed: L1.1, U6.6 (OUTL+)
unnamed: L2.1, U6.7 (OUTL-)
unnamed: L3.1, U6.10 (OUTR+)
unnamed: L4.1, U6.9 (OUTR-)
unnamed: C17.1, U3.4 (BP)
unnamed: R16.2, U4.36 (GPIO4/I2S_LROUT)
PROG: R1.1, R1X.P$1 (1), U2.5 (PROG)
RIGHT: JP5.RING, R11.2, SJ5.2, U1.19 (ADC6), U4.39 (RIGHT)
ROT-A: C24.1, S2.A, U1.1 (PD3(INT1))
ROT-B: C25.1, S2.B, U1.26 (PC3(ADC3))
ROT-LEDB: R26.1, U1.9 (PD5(T1))
ROT-LEDG: R25.1, U1.24 (PC1(ADC1))
ROT-LEDR: R24.1, U1.14 (PB2(SS/OC1B))
ROT-SW: R2.2, S2.3 (SW), U1.2 (PD4(XCK/T0))
RST: C4.2, JP4.5, R3.1, U1.29 (PC6(/RESET))
SCK: JP4.3, U1.17 (PB5(SCK)), U4.28 (SCLK), U7.5 (SCK)
SD-CS: U1.13 (PB1(OC1A)), U7.2 (CS)
SPKL+: C32.1, L3.2, ST6.1, TP7.1
SPKL-: C33.1, L4.2, ST5.1, TP6.1
SPKR+: C30.1, L1.2, ST8.1, TP9.1
SPKR-: C31.1, L2.2, ST7.1, TP8.1
STAT: R9.1, U2.1 (STAT)
TRIG1: ST12.1, TP1.1, U1.23 (PC0(ADC0))
TRIG2/SDA: R18.2, SJ2.1, SJ2.2, ST1.1, TP2.1, U1.27 (PC4(ADC4/SDA)), U6.19 (SDA)
TRIG3/SCL: R19.2, SJ1.1, SJ1.2, ST2.1, TP3.1, U1.28 (PC5(ADC5/SCL)), U6.17 (SCL)
TRIG4/TXO: JP2.2 (RXI), SJ3.2, ST3.1, TP4.1, U1.31 (PD1(TXD))
TRIG5/RXI: R22.1, ST4.1, TP5.1, U1.30 (PD0(RXD))
VBATT: C10.1, JP1.2, JP3.2, S1.1 (3), U2.3 (VBAT)
VBATT_SW: C2.A (+), C22.A (+), C23.1, D1.C, S1.2, U3.1 (IN), U3.3 (EN), U6.4 (PVDDL), U6.5 (PVDDL), U6.11 (PVDDR), U6.12 (PVDDR), U6.13 (AVDD)
VIN: C9.1, JP2.4 (VCC), LED2.A, ST10.1, TP11.1, U2.4 (VIN)

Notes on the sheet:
Spark Fun Electronics
N. Seidle, M. Grusin
microSD
Power
Audio Jack (line-level)
VS1053 MP3 decoder
Charging
FTDI
Sew taps
Speaker amplifier
D3~
D5~
D6~
D9~
D10~
D11~
D12
D13
1:00
12:00
Programming
Rotary encoder
GPIO1
LOW
HIGH
MODE
MP3
MIDI
Microprocessor
2:00
3:00
4:00
5:00
6:00
7:00
8:00
9:00
10:00
11:00
OPERATION RANGE: 3.7V - 6V

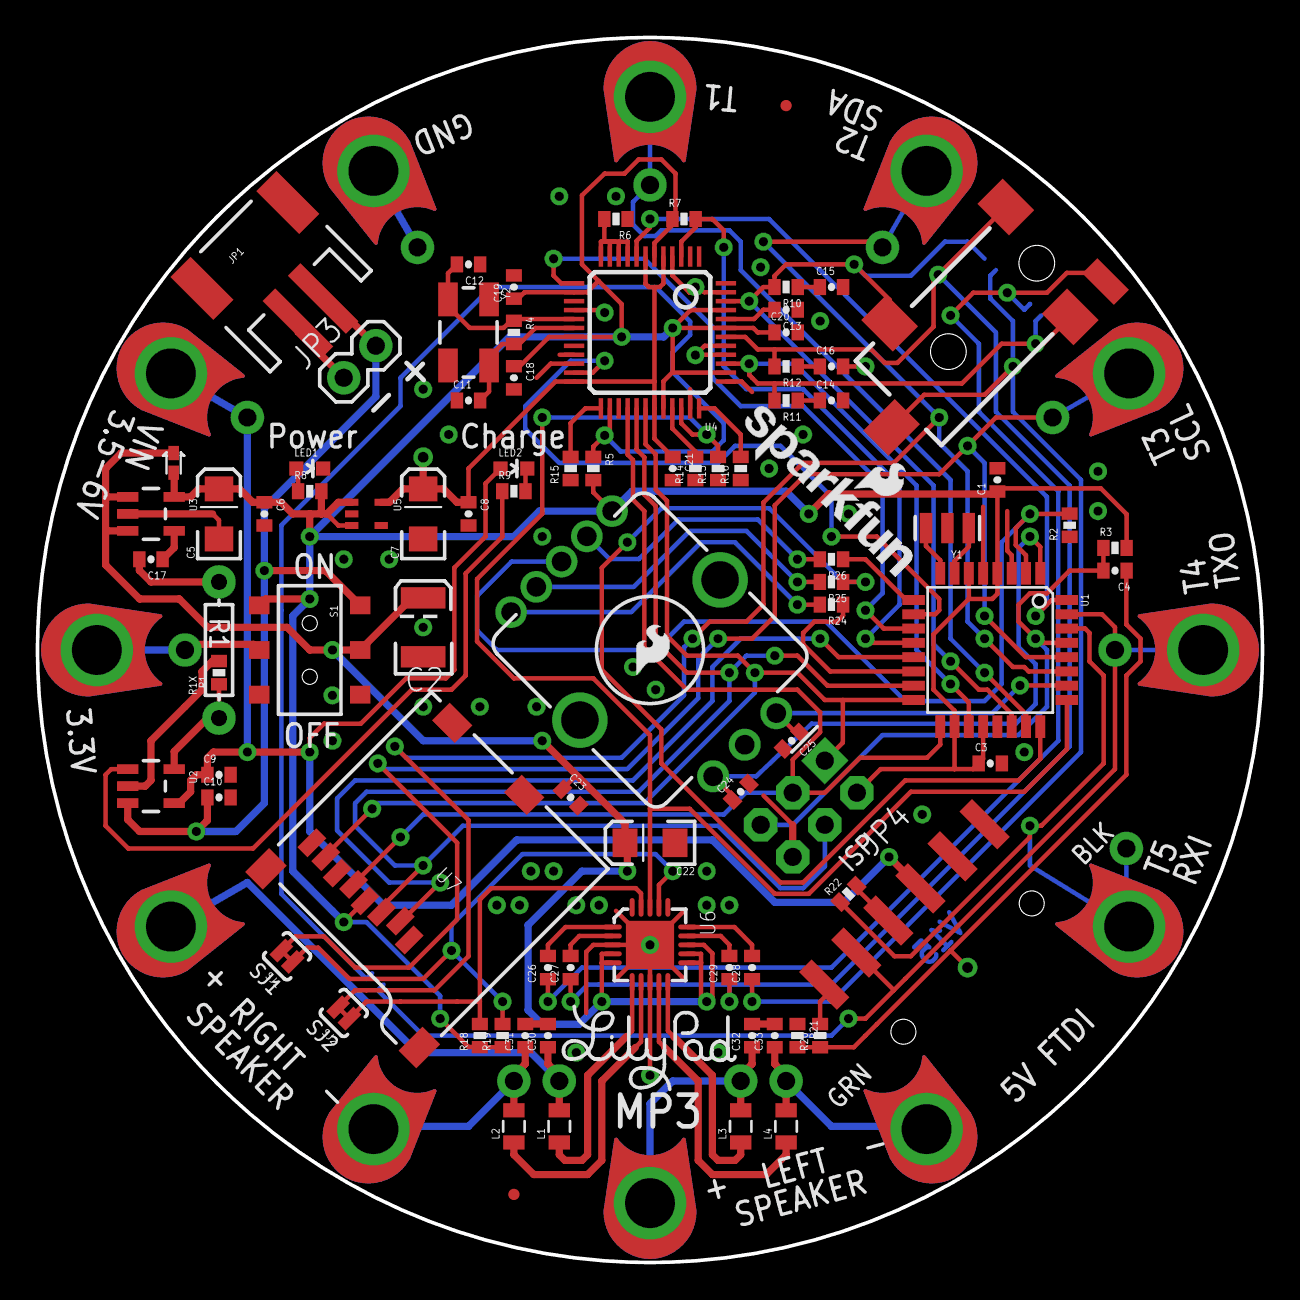
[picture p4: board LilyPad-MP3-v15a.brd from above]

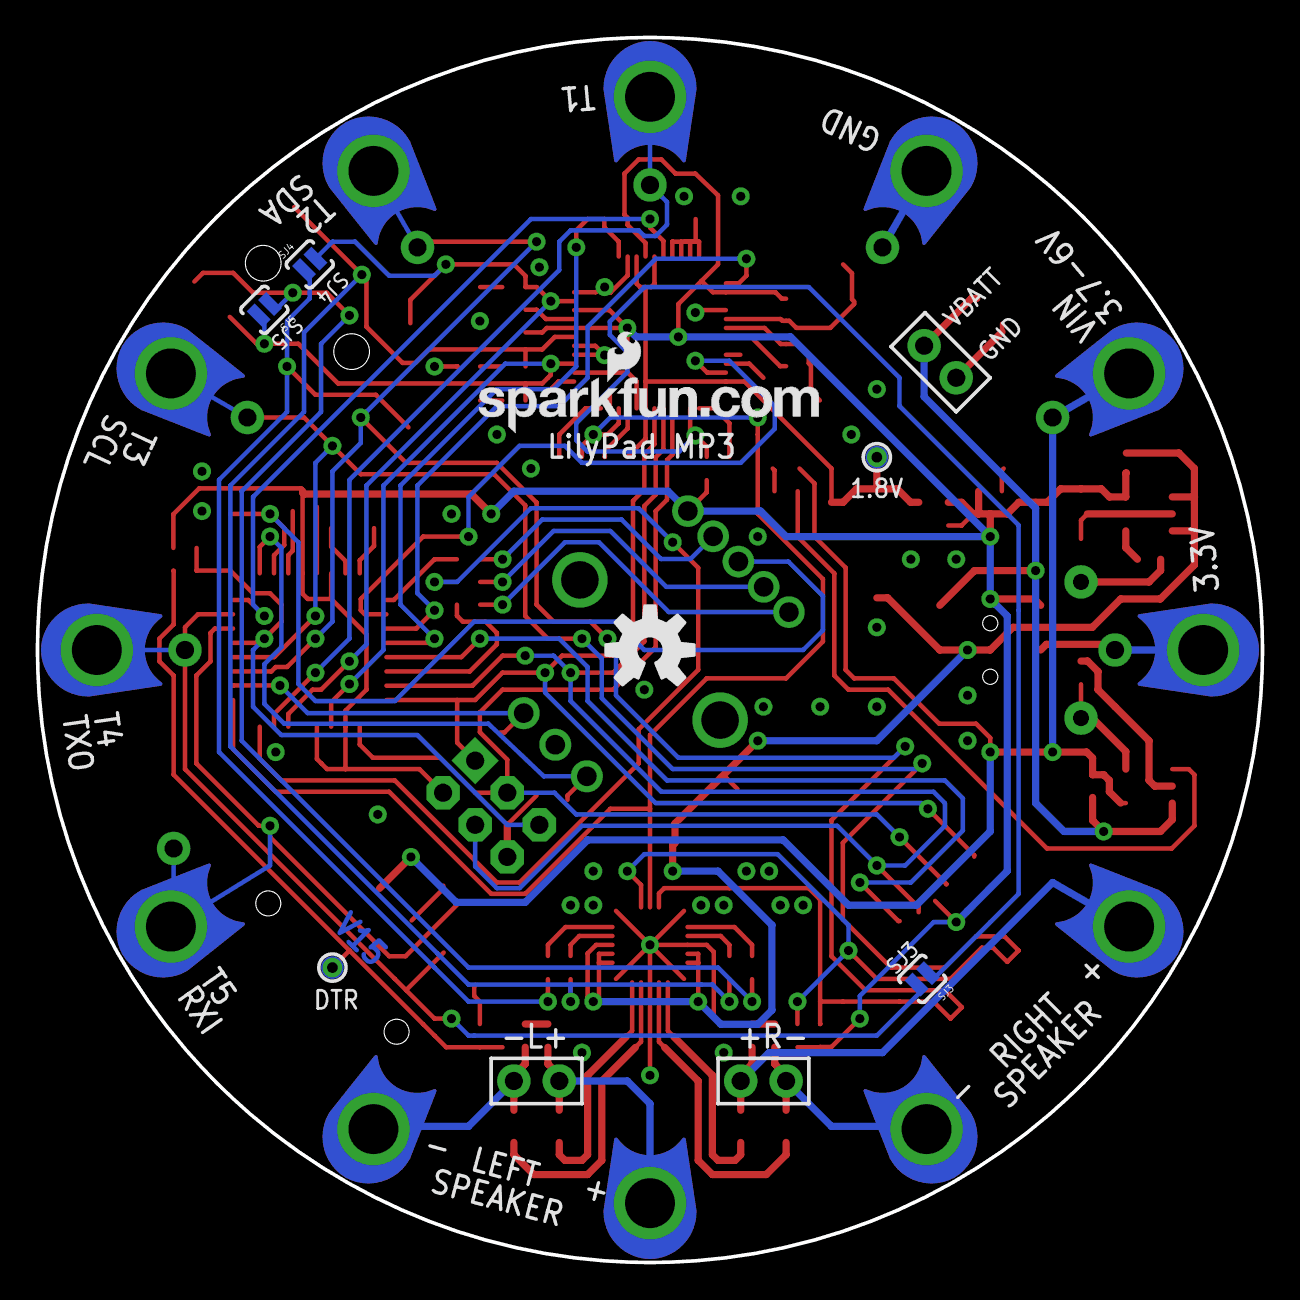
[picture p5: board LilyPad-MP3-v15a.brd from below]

Board: 2 copper layers, 68.6 x 68.6 mm, 121 parts (7 on the bottom side), 69 nets.

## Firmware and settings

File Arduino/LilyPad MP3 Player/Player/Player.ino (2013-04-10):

// "Player" example sketch for Lilypad MP3 Player
// Mike Grusin, SparkFun Electronics
// http://www.sparkfun.com

// This sketch turns the Lilypad MP3 Player into a basic MP3
// player that you can control with the optional rotary encoder.

// HARDWARE

// To use this sketch, an optional RGB rotary encoder must be soldered
// to the MP3 Player board. The board is designed to hold SparkFun
// part number COM-10892. https://www.sparkfun.com/products/10982

// SOFTWARE

// This sketch requires the following libraries. These are included
// in the Lilypad MP3 Player firmware zip file and must be copied to
// a "libraries" folder in your Arduino sketch directory:

// Uses the SdFat library by William Greiman, which is supplied
// with this archive, or download from http://code.google.com/p/sdfatlib/

// Uses the SFEMP3Shield library by Porter and Flaga, which is supplied
// with this archive, or download from http://www.billporter.info/

// Uses the PinChangeInt library by Lex Talionis, which is supplied 
// with this archive, or download from http://code.google.com/p/arduino-pinchangeint/

// BASIC OPERATION:

// Place your audio files in the root directory of the SD card.
// Your files MUST have one of the following extensions: MP3, WAV,
// MID (MIDI), MP4, WMA, AAC, FLA, OGG. Note that this is solely to
// prevent the VS1053 from locking up from being fed non-audio data
// (files without one of the above extensions are quietly skipped).
// You can rename any playable file to any of the above extensions,
// or add additional extensions to the isPlayable() function below.
// See the VS1053 datasheet for the audio file types it can play.

// The player has two modes, TRACK and VOLUME. In TRACK mode, turning
// the knob will move to the next or previous track. In VOLUME mode,
// turning the knob will increase or decrease the volume.

// You can tell what mode you're in by the color of the RGB LED in the
// knob of the rotary encoder. TRACK mode is red, VOLUME mode is green.

// To switch between modes, hold down the button on the rotary encoder
// until the color changes (more than one second).

// To start and stop playback, press the button on the rotary encoder
// *quickly* (less than one second). When the player is playing, it
// will stubbornly keep playing; starting new tracks when the previous
// one ends, and switching to new tracks if you turn the knob in TRACK
// mode. When the player is stopped, it will not start playing until
// you press the button *quickly*, but it will silently change tracks
// or adjust the volume if you turn the knob.

// SERIAL DEBUGGING

// This sketch can output serial debugging information if desired
// by changing the global variable "debugging" to true. Note that
// this will take away trigger inputs 4 and 5, which are shared 
// with the TX and RX lines. You can keep these lines connected to
// trigger switches and use the serial port as long as the triggers
// are normally open (not grounded) and remain ungrounded while the
// serial port is in use.

// License:
// We use the "beerware" license for our firmware. You can do
// ANYTHING you want with this code. If you like it, and we meet
// someday, you can, but are under no obligation to, buy me a
// (root) beer in return.

// Have fun! 
// -your friends at SparkFun

// Revision history:
// 1.0 initial release MDG 2013/1/31

// Required libraries:

#include <SPI.h>
#include <SdFat.h>
#include <SdFatUtil.h>
#include <SFEMP3Shield.h>
#include <PinChangeInt.h>

// Set debugging to true to get serial messages:

boolean debugging = true;

// Possible modes (first and last are there to make
// rotating through them easier):

#define FIRST_MODE 0
#define TRACK 0
#define VOLUME 1
#define LAST_MODE 1

// Initial mode for the rotary encoder. TRACK lets you
// select audio tracks, VOLUME lets you change the volume.
// In any mode, a quick press will start and stop playback.
// A longer press will switch to the next mode.

unsigned char rotary_mode = TRACK;

// Initial volume for the MP3 chip. 0 is the loudest, 255
// is the lowest.

unsigned char volume = 40;

// Start up *not* playing:

boolean playing = false;

// Set loop_all to true if you would like to automatically
// start playing the next file after the current one ends:

boolean loop_all = true;

// LilyPad MP3 pin definitions:

#define TRIG1 A0
#define ROT_LEDG A1
#define SHDN_GPIO1 A2
#define ROT_B A3
#define TRIG2_SDA A4
#define TRIG3_SCL A5
#define RIGHT A6
#define LEFT A7

#define TRIG5_RXI 0
#define TRIG4_TXO 1
#define MP3_DREQ 2
#define ROT_A 3
#define ROT_SW 4
#define ROT_LEDB 5
#define MP3_CS 6
#define MP3_DCS 7
#define MP3_RST 8
#define SD_CS 9
#define ROT_LEDR 10
#define MOSI 11
#define MISO 12
#define SCK 13

// RGB LED colors (for common anode LED, 0 is on, 1 is off)

#define OFF B111
#define RED B110
#define GREEN B101
#define YELLOW B100
#define BLUE B011
#define PURPLE B010
#define CYAN B001
#define WHITE B000

// Global variables and flags for interrupt request functions:

volatile int rotary_counter = 0; // Current "position" of rotary encoder (increments CW) 
volatile boolean rotary_change = false; // Will turn true if rotary_counter has changed
volatile boolean rotary_direction; // Direction rotary encoder was turned (true = CW)
volatile boolean button_pressed = false; // Will turn true if the button has been pushed
volatile boolean button_released = false; // Will turn true if the button has been released (sets button_downtime)
volatile unsigned long button_downtime = 0L; // ms the button was pushed before release
char track[13];

// Library objects:

SdFat sd;
SdFile file;
SFEMP3Shield MP3player;


void setup()
{
  byte result;

  if (debugging)
  {
    Serial.begin(9600);
    Serial.println(F("Lilypad MP3 Player"));

    // ('F' places constant strings in program flash to save RAM)

    Serial.print(F("Free RAM = "));
    Serial.println(FreeRam(), DEC);
  }

  // Set up I/O pins:

  pinMode(TRIG1, INPUT);
  digitalWrite(TRIG1, HIGH); // turn on weak pullup
  pinMode(MP3_CS, OUTPUT);
  pinMode(SHDN_GPIO1, OUTPUT);
  pinMode(ROT_B, INPUT);
  digitalWrite(ROT_B, HIGH); // turn on weak pullup
  pinMode(TRIG2_SDA, INPUT);
  digitalWrite(TRIG1, HIGH); // turn on weak pullup
  pinMode(TRIG3_SCL, INPUT);
  digitalWrite(TRIG1, HIGH); // turn on weak pullup
  pinMode(TRIG5_RXI, INPUT);
  digitalWrite(TRIG5_RXI, HIGH); // turn on weak pullup
  pinMode(TRIG4_TXO, INPUT);
  digitalWrite(TRIG4_TXO, HIGH); // turn on weak pullup
  pinMode(ROT_A, INPUT);
  digitalWrite(ROT_A, HIGH); // turn on weak pullup
  pinMode(ROT_SW, INPUT);
  // switch is common anode with external pulldown, do not turn on pullup
  pinMode(MP3_DREQ, INPUT);
  pinMode(ROT_LEDB, OUTPUT);
  pinMode(ROT_LEDG, OUTPUT);
  pinMode(MP3_DCS, OUTPUT);
  pinMode(MP3_RST, OUTPUT);
  pinMode(ROT_LEDR, OUTPUT);
  pinMode(SD_CS, OUTPUT);
  pinMode(MOSI, OUTPUT);
  pinMode(MISO, INPUT);
  pinMode(SCK, OUTPUT);

 // Turn off amplifier chip / turn on MP3 mode:

  digitalWrite(SHDN_GPIO1, LOW);
  setLEDcolor(OFF);

  // Initialize the SD card:

  if (debugging) Serial.println(F("Initializing SD card... "));

  result = sd.begin(SD_SEL, SPI_HALF_SPEED);

  if (result != 1)
  {
    if (debugging) Serial.println(F("error, halting"));
    errorBlink(1,RED);
  }
  else 
    if (debugging) Serial.println(F("OK"));
 
  //Initialize the MP3 chip:
  
  if (debugging) Serial.println(F("Initializing MP3 chip... "));

  result = MP3player.begin();

  // Check result, 0 and 6 are OK:
  
  if((result != 0) && (result != 6))
  {
    if (debugging)
    {
      Serial.print(F("error "));
      Serial.println(result);
    }
    errorBlink(result,BLUE);
  }
  else
    if (debugging) Serial.println(F("OK"));
  
  // Set up interrupts. We'll use the standard external interrupt
  // pin for the rotary, but we'll use the pin change interrupt
  // library for the button:

  attachInterrupt(1,rotaryIRQ,CHANGE);
  PCintPort::attachInterrupt(ROT_SW, &buttonIRQ, CHANGE);

  // Get initial track:
  
  sd.chdir("/",true); // Index beginning of root directory
  getNextTrack();
  if (debugging)
  {
    Serial.print(F("current track: "));
    Serial.println(track);
  }
  
  // Set initial volume (same for both left and right channels)
  
  MP3player.setVolume(volume, volume);
  
  // Initial mode for the rotary encoder

  LEDmode(rotary_mode);
  
  // Uncomment to get a directory listing of the SD card:
  // sd.ls(LS_R | LS_DATE | LS_SIZE);

  // Turn on amplifier chip:
  
  digitalWrite(SHDN_GPIO1, HIGH);
  delay(2);
}


void buttonIRQ()
{
  // Button press interrupt request function (IRQ).
  // This function is called *automatically* when the button
  // changes state.

  // Process rotary encoder button presses and releases, including
  // debouncing (extra "presses" from noisy switch contacts).

  // If button is pressed, the button_pressed flag is set to true.
  // (Manually set this to false after handling the change.)

  // If button is released, the button_released flag is set to true,
  // and button_downtime will contain the duration of the button
  // press in ms. (Set this to false after handling the change.)

  // Raw information from PinChangeInt library:
  
  // Serial.print("pin: ");
  // Serial.print(PCintPort::arduinoPin);
  // Serial.print(" state: ");
  // Serial.println(PCintPort::pinState);
  
  static boolean button_state = false;
  static unsigned long start, end;
    
  if ((PCintPort::pinState == HIGH) && (button_state == false)) 
  // Button was up, but is currently being pressed down
  {
    // Discard button presses too close together (debounce)
    start = millis();
    if (start > (end + 10)) // 10ms debounce timer
    {
      button_state = true;
      button_pressed = true;
    }
  }
  else if ((PCintPort::pinState == LOW) && (button_state == true))
  // Button was down, but has just been released
  {
    // Discard button releases too close together (debounce)
    end = millis();
    if (end > (start + 10)) // 10ms debounce timer
    {
      button_state = false;
      button_released = true;
      button_downtime = end - start;
    }
  }
}


void rotaryIRQ()
{
  // Rotary encoder interrupt request function (IRQ).
  // This function is called *automatically* when the
  // rotary encoder changes state.

  // Process input from the rotary encoder.
  // The rotary "position" is held in rotary_counter, increasing
  // for CW rotation (changes by one per detent).
  
  // If the position changes, rotary_change will be set true.
  // (You may manually set this to false after handling the change).

  // This function will automatically run when rotary encoder input A
  // transitions in either direction (low to high or high to low).
  // By saving the state of the A and B pins through two interrupts,
  // we'll determine the direction of rotation.
  
  // Int rotary_counter will be updated with the new value, and boolean
  // rotary_change will be true if there was a value change.
  
  // Based on concepts from Oleg at circuits@home (http://www.circuitsathome.com/mcu/rotary-encoder-interrupt-service-routine-for-avr-micros)
  // Unlike Oleg's original code, this code uses only one interrupt and
  // has only two transition states; it has less resolution but needs only
  // one interrupt, is very smooth, and handles switchbounce well.
  
  static unsigned char rotary_state = 0; // Current and previous encoder states
  
  rotary_state <<= 2;  // Remember previous state
  rotary_state |= (digitalRead(ROT_A) | (digitalRead(ROT_B) << 1));  // Mask in current state
  rotary_state &= 0x0F; // Zero upper nybble

  //Serial.println(rotary_state,HEX);

  if (rotary_state == 0x09) // From 10 to 01, increment counter. Also try 0x06 if unreliable.
  {
    rotary_counter++;
    rotary_direction = true;
    rotary_change = true;
  }
  else if (rotary_state == 0x03) // From 00 to 11, decrement counter. Also try 0x0C if unreliable.
  {
    rotary_counter--;
    rotary_direction = false;
    rotary_change = true;
  }
}


void loop()
{
  // "Static" variables are initalized once the first time
  // the loop runs, but they keep their values through
  // successive loops.
  
  static boolean button_down = false;
  static unsigned long int button_down_start, button_down_time;
  
  // rotaryIRQ() sets the flag rotary_counter to true
  // if the knob position has changed. We can use this flag
  // to do something in the main loop() each time there's
  // a change. We'll clear this flag when we're done, which
  // lets us run this if() once for each change.
  
  if (rotary_change)
  {
    switch (rotary_mode)
    {
      case TRACK:
      
        // Before switching to a new audio file, we MUST
        // stop playing before accessing the SD directory:
       
        if (playing)
          stopPlaying();
      
        // Get the next file:
      
        if (rotary_direction)
          getNextTrack();
        else
          getPrevTrack();
      
        // If we were previously playing, let's start again!
      
        if (playing) startPlaying(); 

        if (debugging)
        {
          Serial.print(F("current track "));
          Serial.println(track);
        }
        break;
      
      case VOLUME:

        // Change the volume. Easy.
        
        changeVolume(rotary_direction);
        break;
    }
    rotary_change = false; // Clear flag
  }

  // The button IRQ also sets several flags to true, one for
  // button_pressed, one for button_released. Like the rotary
  // flag, we'll clear these when we're done handling them:

  if (button_pressed)
  {
    if (debugging) Serial.println(F("button press"));

    button_pressed = false; // Clear flag

    // We'll set another flag saying the button is now down
    // this is so we can keep track of how long the button
    // is being held down. (We can't do this in interrupts,
    // because the button state doesn't change while it's
    // being held down):

    button_down = true;
    button_down_start = millis();
  }

  if (button_released)
  {
    if (debugging)
    {
      Serial.print(F("button release, downtime: "));
      Serial.println(button_downtime,DEC);
    }
    
    // For quick button presses, start or stop playback:
    
    if (button_downtime < 1000)
    {
      playing = !playing;
      if (playing)
        startPlaying();
      else
        stopPlaying();
    }

    button_released = false; // Clear flags
    button_down = false;
  }

  // Now we can keep track of how long the button is being
  // held down, and perform actions based on that time.
  // This lets us implement the "hold down for one second
  // to change mode" action:

  if (button_down)
  {
    button_down_time = millis() - button_down_start;

    if (button_down_time > 1000)
    {
      // Switch to next mode

      rotary_mode++;

      // Loop around if necessary

      if (rotary_mode > LAST_MODE) rotary_mode = FIRST_MODE;

      // Set LED to mode color

      LEDmode(rotary_mode);

      if (debugging)
      {
        Serial.print(F("mode "));
        Serial.println(rotary_mode);
      }
      
      // Reset counter so holding the button will continue
      // switching through modes:
      
      button_down_start = millis();
    }
  }
  
  // Handle "last track ended" situations
  // (should we play the next track?)
  
  // Are we in "playing" mode, and has the
  // current file ended?
  
  if (playing && !MP3player.isPlaying())
  {
    getNextTrack(); // Set up for next track
    
    // If loop_all is true, start the next track
    
    if (loop_all)
    {
      startPlaying();
    }
    else
      playing = false;
  }
}


void changeVolume(boolean direction)
{
  // Increment or decrement the volume.
  // This is handled internally in the VS1053 MP3 chip.
  // Lower numbers are louder (0 is the loudest).
  
  if (volume < 255 && direction == false)
    volume += 2;
  
  if (volume > 0 && direction == true)
    volume -= 2;

  MP3player.setVolume(volume, volume);

  if (debugging)
  {
    Serial.print(F("volume "));
    Serial.println(volume);
  }
}


void getNextTrack()
{
  // Get the next playable track (check extension to be
  // sure it's an audio file)
  
  do
    getNextFile();
  while(isPlayable() != true);
}


void getPrevTrack()
{
  // Get the previous playable track (check extension to be
  // sure it's an audio file)

  do
    getPrevFile();
  while(isPlayable() != true);
}


void getNextFile()
{
  // Get the next file (which may be playable or not)

  int result = (file.openNext(sd.vwd(), O_READ));

  // If we're at the end of the directory,
  // loop around to the beginning:
  
  if (!result)
  {
    sd.chdir("/",true);
    getNextTrack();
    return;
  }
  file.getFilename(track);  
  file.close();
}


void getPrevFile()
{
  // Get the previous file (which may be playable or not)
  
  char test[13], prev[13];

  // Getting the previous file is tricky, since you can
  // only go forward when reading directories.

  // To handle this, we'll save the name of the current
  // file, then keep reading all the files until we loop
  // back around to where we are. While doing this we're
  // saving the last file we looked at, so when we get
  // back to the current file, we'll return the previous
  // one.
  
  // Yeah, it's a pain.

  strcpy(test,track);

  do
  {
    strcpy(prev,track);
    getNextTrack();
  }
  while(strcasecmp(track,test) != 0);
  
  strcpy(track,prev);
}


void startPlaying()
{
  int result;
  
  if (debugging)
  {
    Serial.print(F("playing "));
    Serial.print(track);
    Serial.print(F("..."));
  }  

  result = MP3player.playMP3(track);

  if (debugging)
  {
    Serial.print(F(" result "));
    Serial.println(result);  
  }
}


void stopPlaying()
{
  if (debugging) Serial.println(F("stopping playback"));
  MP3player.stopTrack();
}


boolean isPlayable()
{
  // Check to see if a filename has a "playable" extension.
  // This is to keep the VS1053 from locking up if it is sent
  // unplayable data.

  char *extension;
  
  extension = strrchr(track,'.');
  extension++;
  if (
    (strcasecmp(extension,"MP3") == 0) ||
    (strcasecmp(extension,"WAV") == 0) ||
    (strcasecmp(extension,"MID") == 0) ||
    (strcasecmp(extension,"MP4") == 0) ||
    (strcasecmp(extension,"WMA") == 0) ||
    (strcasecmp(extension,"FLA") == 0) ||
    (strcasecmp(extension,"OGG") == 0) ||
    (strcasecmp(extension,"AAC") == 0)
  )
    return true;
  else
    return false;
}


void LEDmode(unsigned char mode)
{
  // Change the RGB LED to a specific color for each mode
  // (See #defines at start of sketch for colors.)

  switch (mode)
  {
    case TRACK:
      setLEDcolor(RED);
      break;
    case VOLUME:
      setLEDcolor(GREEN);
      break;
    default:
      setLEDcolor(OFF);
  }
}


void setLEDcolor(unsigned char color)
{
  // Set the RGB LED in the (optional) rotary encoder
  // to a specific color. See the color #defines at the
  // start of this sketch.

  digitalWrite(ROT_LEDR,color & B001);
  digitalWrite(ROT_LEDG,color & B010);
  digitalWrite(ROT_LEDB,color & B100);  
}


void errorBlink(int blinks, byte color)
{
  // This function will blink the RGB LED in the rotary encoder
  // (optional) a given number of times and repeat forever.
  // This is so you can see error codes without having to use
  // the serial monitor window.

  int x;

  while(true) // Loop forever
  {
    for (x=0; x < blinks; x++) // Blink a given number of times
    {
      setLEDcolor(color);
      delay(250);
      setLEDcolor(OFF);
      delay(250);
    }
    delay(1500); // Longer pause between blink-groups
  }
}

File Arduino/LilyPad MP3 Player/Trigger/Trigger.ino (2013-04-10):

// "Trigger" example sketch for Lilypad MP3 Player
// Mike Grusin, SparkFun Electronics
// http://www.sparkfun.com

// This sketch (which is preloaded onto the board by default),
// will play a specific audio file when one of the five trigger
// inputs (labeled T1 - T5) is momentarily grounded.

// You can place up to five audio files on the micro-SD card.
// These files should have the desired trigger number (1 to 5)
// as the first character in the filename. The rest of the
// filename can be anything you like. Long file names will work,
// but will be translated into short 8.3 names. We recommend using
// 8.3 format names without spaces, but the following characters
// are OK: .$%'-_@~`!(){}^#&. The VS1053 can play a variety of 
// audio formats, see the datasheet for information.

// By default, a new trigger will interrupt a playing file, except
// itself. (In other words, a new trigger won't restart an 
// already-playing file). You can easily change this behavior by
// modifying the global variables "interrupt" and "interruptself"
// below.

// This sketch can output serial debugging information if desired
// by changing the global variable "debugging" to true. Note that
// this will take away trigger inputs 4 and 5, which are shared 
// with the TX and RX lines. You can keep these lines connected to
// trigger switches and use the serial port as long as the triggers
// are normally open (not grounded) and remain ungrounded while the
// serial port is in use.

// Uses the SdFat library by William Greiman, which is supplied
// with this archive, or download from http://code.google.com/p/sdfatlib/

// Uses the SFEMP3Shield library by Bill Porter, which is supplied
// with this archive, or download from http://www.billporter.info/

// License:
// We use the "beerware" license for our firmware. You can do
// ANYTHING you want with this code. If you like it, and we meet
// someday, you can, but are under no obligation to, buy me a
// (root) beer in return.

// Have fun! 
// -your friends at SparkFun

// Revision history:
// 1.0 initial release MDG 2012/11/01


// We'll need a few libraries to access all this hardware!

#include <SPI.h>            // To talk to the SD card and MP3 chip
#include <SdFat.h>          // SD card file system
#include <SFEMP3Shield.h>   // MP3 decoder chip

// Constants for the trigger input pins, which we'll place
// in an array for convenience:

const int TRIG1 = A0;
const int TRIG2 = A4;
const int TRIG3 = A5;
const int TRIG4 = 1;
const int TRIG5 = 0;
int trigger[5] = {TRIG1,TRIG2,TRIG3,TRIG4,TRIG5};

// And a few outputs we'll be using:

const int ROT_LEDR = 10; // Red LED in rotary encoder (optional)
const int EN_GPIO1 = A2; // Amp enable + MIDI/MP3 mode select
const int SD_CS = 9;     // Chip Select for SD card

// Create library objects:

SFEMP3Shield MP3player;
SdFat sd;

// Set debugging = true if you'd like status messages sent 
// to the serial port. Note that this will take over trigger
// inputs 4 and 5. (You can leave triggers connected to 4 and 5
// and still use the serial port, as long as you're careful to
// NOT ground the triggers while you're using the serial port).

boolean debugging = false;

// Set interrupt = false if you would like a triggered file to
// play all the way to the end. If this is set to true, new
// triggers will stop the playing file and start a new one.

boolean interrupt = true;

// Set interruptself = true if you want the above rule to also
// apply to the same trigger. In other words, if interrupt = true
// and interruptself = false, subsequent triggers on the same
// file will NOT start the file over. However, a different trigger
// WILL stop the original file and start a new one.

boolean interruptself = false;

// We'll store the five filenames as arrays of characters.
// "Short" (8.3) filenames are used, followed by a null character.

char filename[5][13];


void setup()
{
  int x, index;
  SdFile file;
  byte result;
  char tempfilename[13];

  // Set the five trigger pins as inputs, and turn on the 
  // internal pullup resistors:
  
  for (x = 0; x <= 4; x++)
  {
    pinMode(trigger[x],INPUT);
    digitalWrite(trigger[x],HIGH);
  }

  // If serial port debugging is inconvenient, you can connect
  // a LED to the red channel of the rotary encoder to blink
  // startup error codes:
  
  pinMode(ROT_LEDR,OUTPUT);
  digitalWrite(ROT_LEDR,HIGH);  // HIGH = off

  // The board uses a single I/O pin to select the
  // mode the MP3 chip will start up in (MP3 or MIDI),
  // and to enable/disable the amplifier chip:
  
  pinMode(EN_GPIO1,OUTPUT);
  digitalWrite(EN_GPIO1,LOW);  // MP3 mode / amp off


  // If debugging is true, initialize the serial port:
  // (The 'F' stores constant strings in flash memory to save RAM)
  
  if (debugging)
  {
    Serial.begin(9600);
    Serial.println(F("Lilypad MP3 Player trigger sketch"));
  }
  
  // Initialize the SD card; SS = pin 9, half speed at first

  if (debugging) Serial.print(F("initialize SD card... "));

  result = sd.begin(SD_CS, SPI_HALF_SPEED); // 1 for success
  
  if (result != 1) // Problem initializing the SD card
  {
    if (debugging) Serial.print(F("error, halting"));
    errorBlink(1); // Halt forever, blink LED if present.
  }
  else
    if (debugging) Serial.println(F("success!"));
  
  // Start up the MP3 library

  if (debugging) Serial.print(F("initialize MP3 chip... "));

  result = MP3player.begin(); // 0 or 6 for success

  // Check the result, see the library readme for error codes.

  if ((result != 0) && (result != 6)) // Problem starting up
  {
    if (debugging)
    {
      Serial.print(F("error code "));
      Serial.print(result);
      Serial.print(F(", halting."));
    }
    errorBlink(result); // Halt forever, blink red LED if present.
  }
  else
    if (debugging) Serial.println(F("success!"));

  // Now we'll access the SD card to look for any (audio) files
  // starting with the characters '1' to '5':

  if (debugging) Serial.println(F("reading root directory"));

  // Start at the first file in root and step through all of them:

  sd.chdir("/",true);
  while (file.openNext(sd.vwd(),O_READ))
  {
    // get filename

    file.getFilename(tempfilename);

    // Does the filename start with char '1' through '5'?      

    if (tempfilename[0] >= '1' && tempfilename[0] <= '5')
    {
      // Yes! subtract char '1' to get an index of 0 through 4.

      index = tempfilename[0] - '1';
      
      // Copy the data to our filename array.

      strcpy(filename[index],tempfilename);
  
      if (debugging) // Print out file number and name
      {
        Serial.print(F("found a file with a leading "));
        Serial.print(index+1);
        Serial.print(F(": "));
        Serial.println(filename[index]);
      }
    }
    else
      if (debugging)
      {
        Serial.print(F("found a file w/o a leading number: "));
        Serial.println(tempfilename);
      }
      
    file.close();
  }
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

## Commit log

2013-05-02 modified schematic for two pages, created PDF
    [LilyPad-MP3-v15a.sch]
2013-05-10 Updated SdFat library to 20130313 for Arduino 1.0.4
    This update fixes an issue where compiling software using the SdFat
    library under Arduino 1.0.4 failed. The updated SdFat library includes a
    new version of FreeRam() that has been modified to use Arduino's new
    implementation of malloc(). See
    http://arduino.cc/forum/index.php?topic=154033.0 for more information.
2016-02-29 Updated sfe mp3 player to most recent version
    This fixes compiler errors on recent Arduino IDE (1.6.7 etc.)

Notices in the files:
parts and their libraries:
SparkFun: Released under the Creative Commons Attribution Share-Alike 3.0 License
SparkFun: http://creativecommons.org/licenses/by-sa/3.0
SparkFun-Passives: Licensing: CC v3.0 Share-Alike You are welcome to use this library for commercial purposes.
